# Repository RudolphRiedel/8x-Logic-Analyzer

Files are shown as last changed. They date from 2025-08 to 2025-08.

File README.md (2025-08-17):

# 8x-Logic-Analyzer

## what is this?
8 channel RP2350 logic analyzer hardware

This is a contribution project for: https://github.com/gusmanb/logicanalyzer
It might end up as a pull-request someday, however I am using version 6.5 which is still in beta.

## what the heck, why more hardware?

I was intrigued by logicanalyzer project, inexpensive, yet fast and with plenty of channels.
I have no use for 24 channels though, I did not like the daughter-board approach very much
and I had experience with 5V tolerant logic which makes switching the external reference obsolete.
Plus I had not done anything with the RP2350A before.

So I took this as an opportunity to design a RP2350A board.
Limited to 8 channels with no option to cascade, this is plenty for SPI plus four more pins.

I did two hardware revisions so far, the first is up and running, the second is functionally the same
with some details tweaked and I just ordered it.

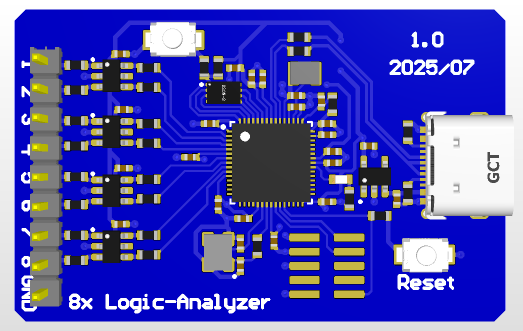
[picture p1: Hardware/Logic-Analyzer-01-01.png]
8x-Logic-Analyzer


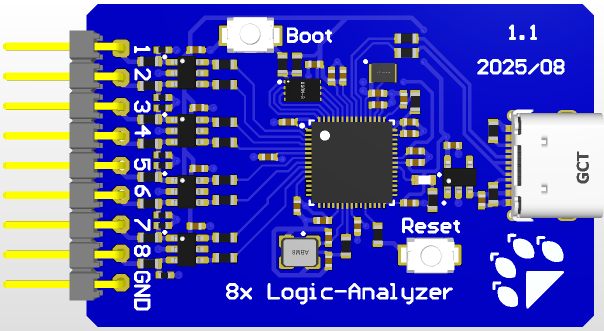
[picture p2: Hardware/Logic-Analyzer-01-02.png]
8x-Logic-Analyzer


This repository has the complete set of files for the Logic-Analyzer-01-02 design.
I just ordered five boards from JLCPCB with the gerber set Logic-Analyzer-01-02.zip, the BOM Logic-Analyzer-01-02_BOM.xlsx and the pick&place list Logic-Analyzer-01-02_CPL.xlsx.

There also is a .pdf included with the schematic: \Hardware\Logic-Analyzer-01-028x_Logic-Analyzer.PDF

## software?

This repository only has a modified version of the LogicAnaylzer_V2 firmware from the V6.5 branch.
I modified the files and added a new board: BOARD_PICO2_8X
To do that I changed CMakeLists.txt, LogicAnalyzer_Board_Settings.h, LogicAnalyzer_Build_Settings.cmake and publish.ps1
And with only 8 channels I was able to tweak the sample buffer from the original 384kiB to 469kiB.

As for the application, I am using the 6.5 beta that was made available here: https://github.com/gusmanb/logicanalyzer/discussions/277

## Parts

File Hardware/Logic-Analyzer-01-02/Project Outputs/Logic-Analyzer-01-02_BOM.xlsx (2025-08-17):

Comment | Designator | Footprint | JLCPCB Part #
100n | C100, C101, C102, C103, C104, C105, C106, C107, C108, C109, C110, C118, C119, C120, C121, C122, C123 | 0402 | C1525
15p | C111, C112 | 0402 | C1548
4µ7 | C113, C114, C115, C116, C117 | 0402 | C23733
red | D100 | 0603 | C2286
AOTA-B201610S3R3-101-T | L100 | 2.0mm x 1.6mm | C42411119
51 | R100, R101, R102, R103, R104, R105, R106, R107, R108, R109, R110, R111, R112, R113, R114, R115 | 0603 | C23197
27 | R116, R117, R121 | 0603 | C25190
1k | R118, R122, R124 | 0603 | C21190
5k1 | R119, R120 | 0603 | C23186
10k | R123, R125 | 0603 | C25804
100k | R126, R127, R128, R129, R130, R131, R132, R133 | 0402 | C25741
TS-1088-AR02016 | S100, S101 | 4x3 mm | C720477
74LVC2G17 | U100, U101, U103, U104 | SOT23-6 | C10429
TPLP5907MFX-3.3 | U102 | SOT23-5 | C5370990
XT25F16FDTIGT-S | U105 | USON8 | C29781641
RP2350A | U106 | QFN-60 | C42411118
12MHz | V100 | 3.2mm x 2.5mm | C20625731
1x9 2,54mm | X100 |  | do not populate
USB-C | X101 |  | C2765186

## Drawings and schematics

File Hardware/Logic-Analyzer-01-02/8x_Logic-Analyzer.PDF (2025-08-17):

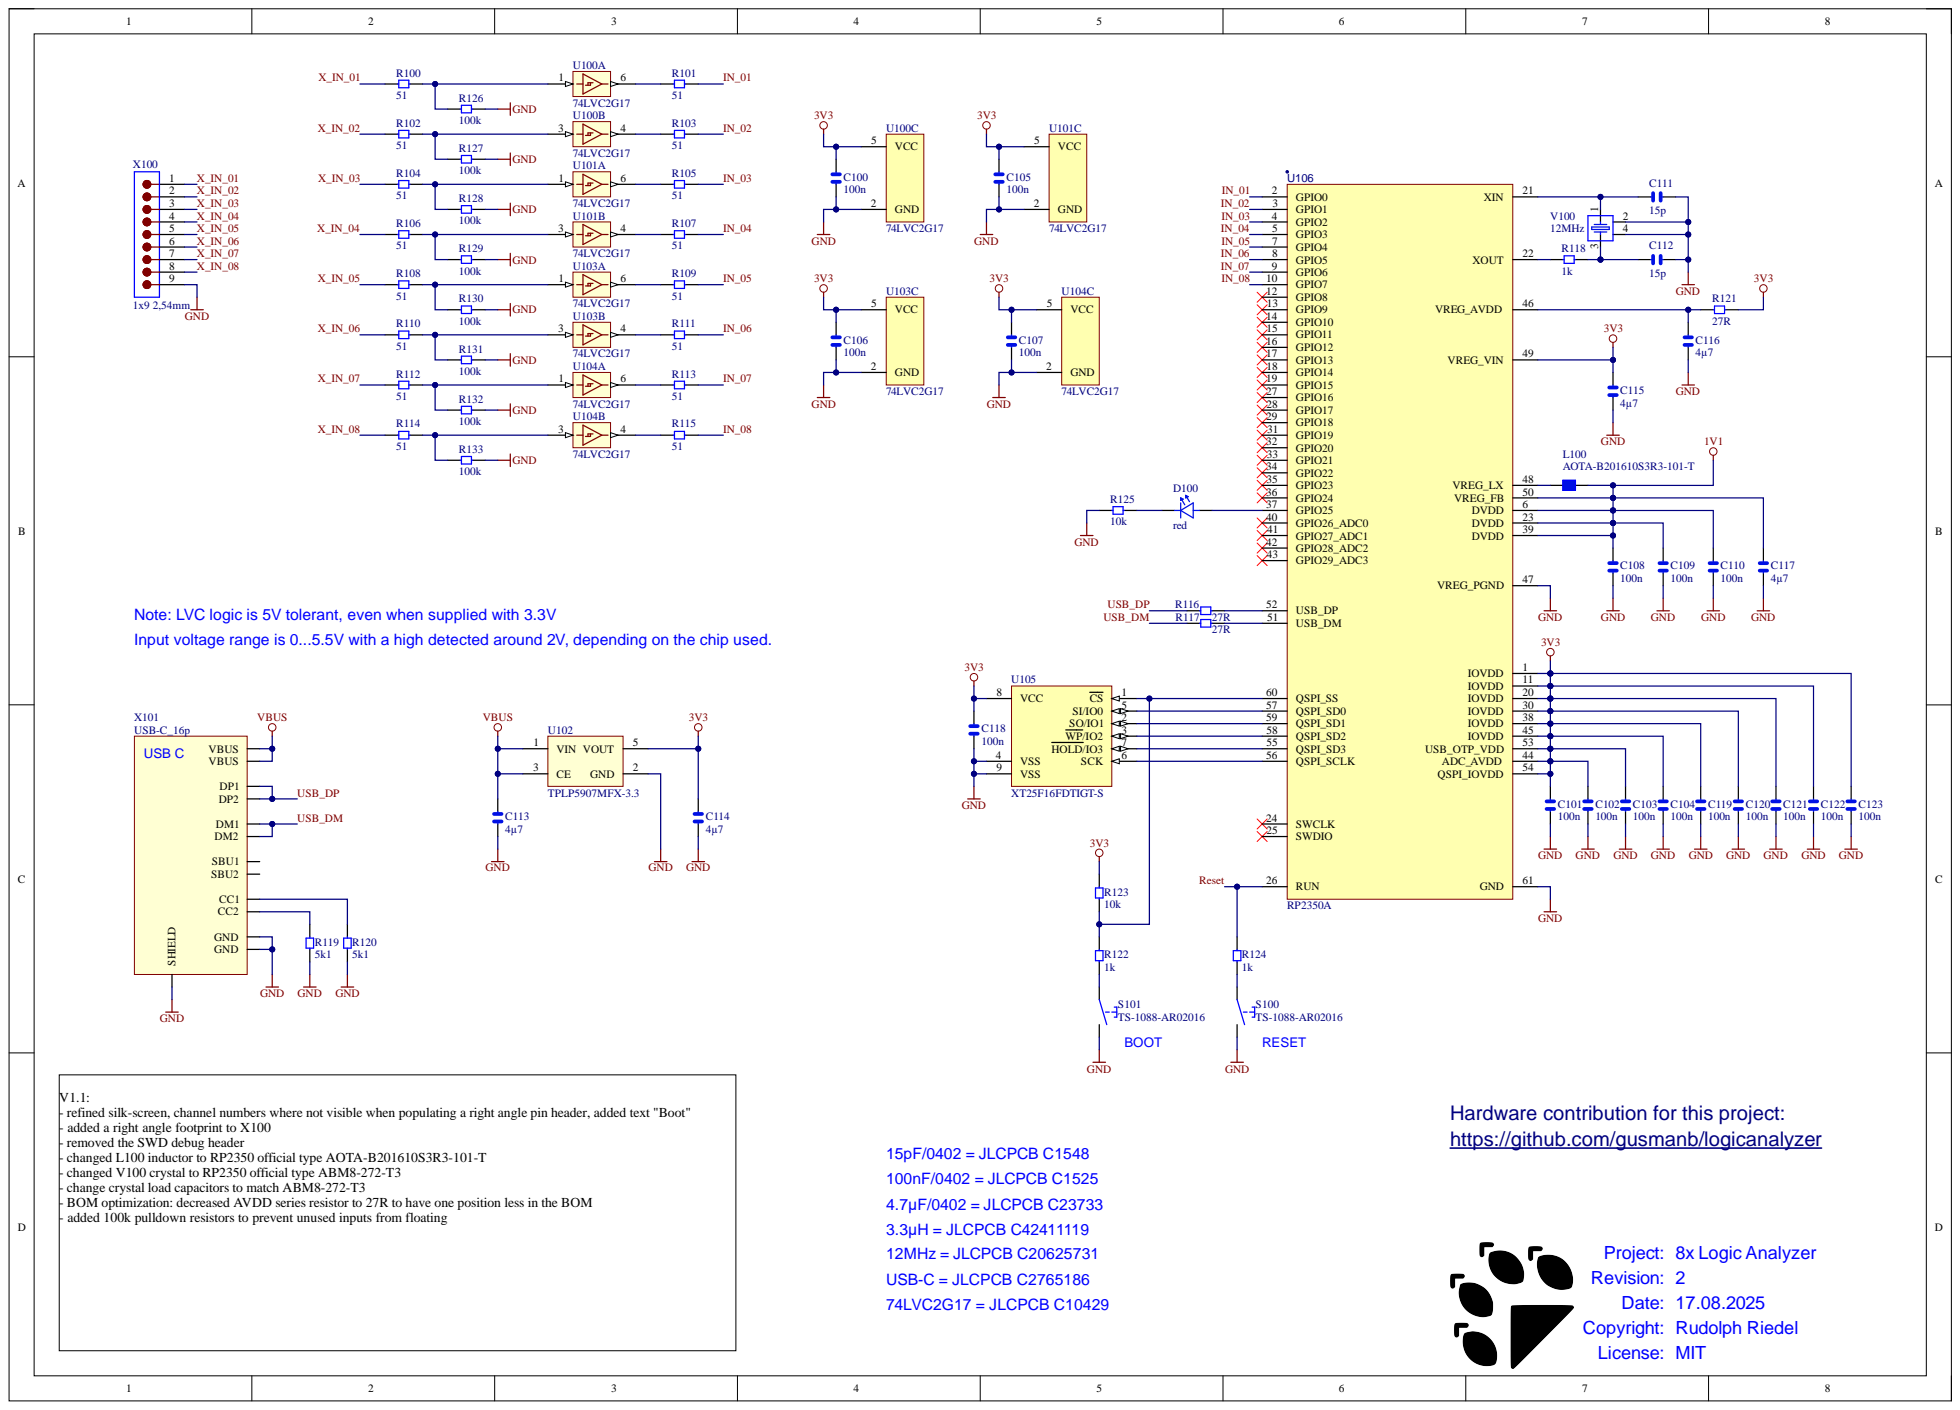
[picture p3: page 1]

LVC logic is 5V tolerant, even when
Note:
Input

voltage range is 0...5.5V with a high detected around 2V, depending on the

lk-screen, channel numbers

ing a right angle pin header

Hardware contribution for this project:
https://github.com/gusmanb/logicanalyz

to have one posi

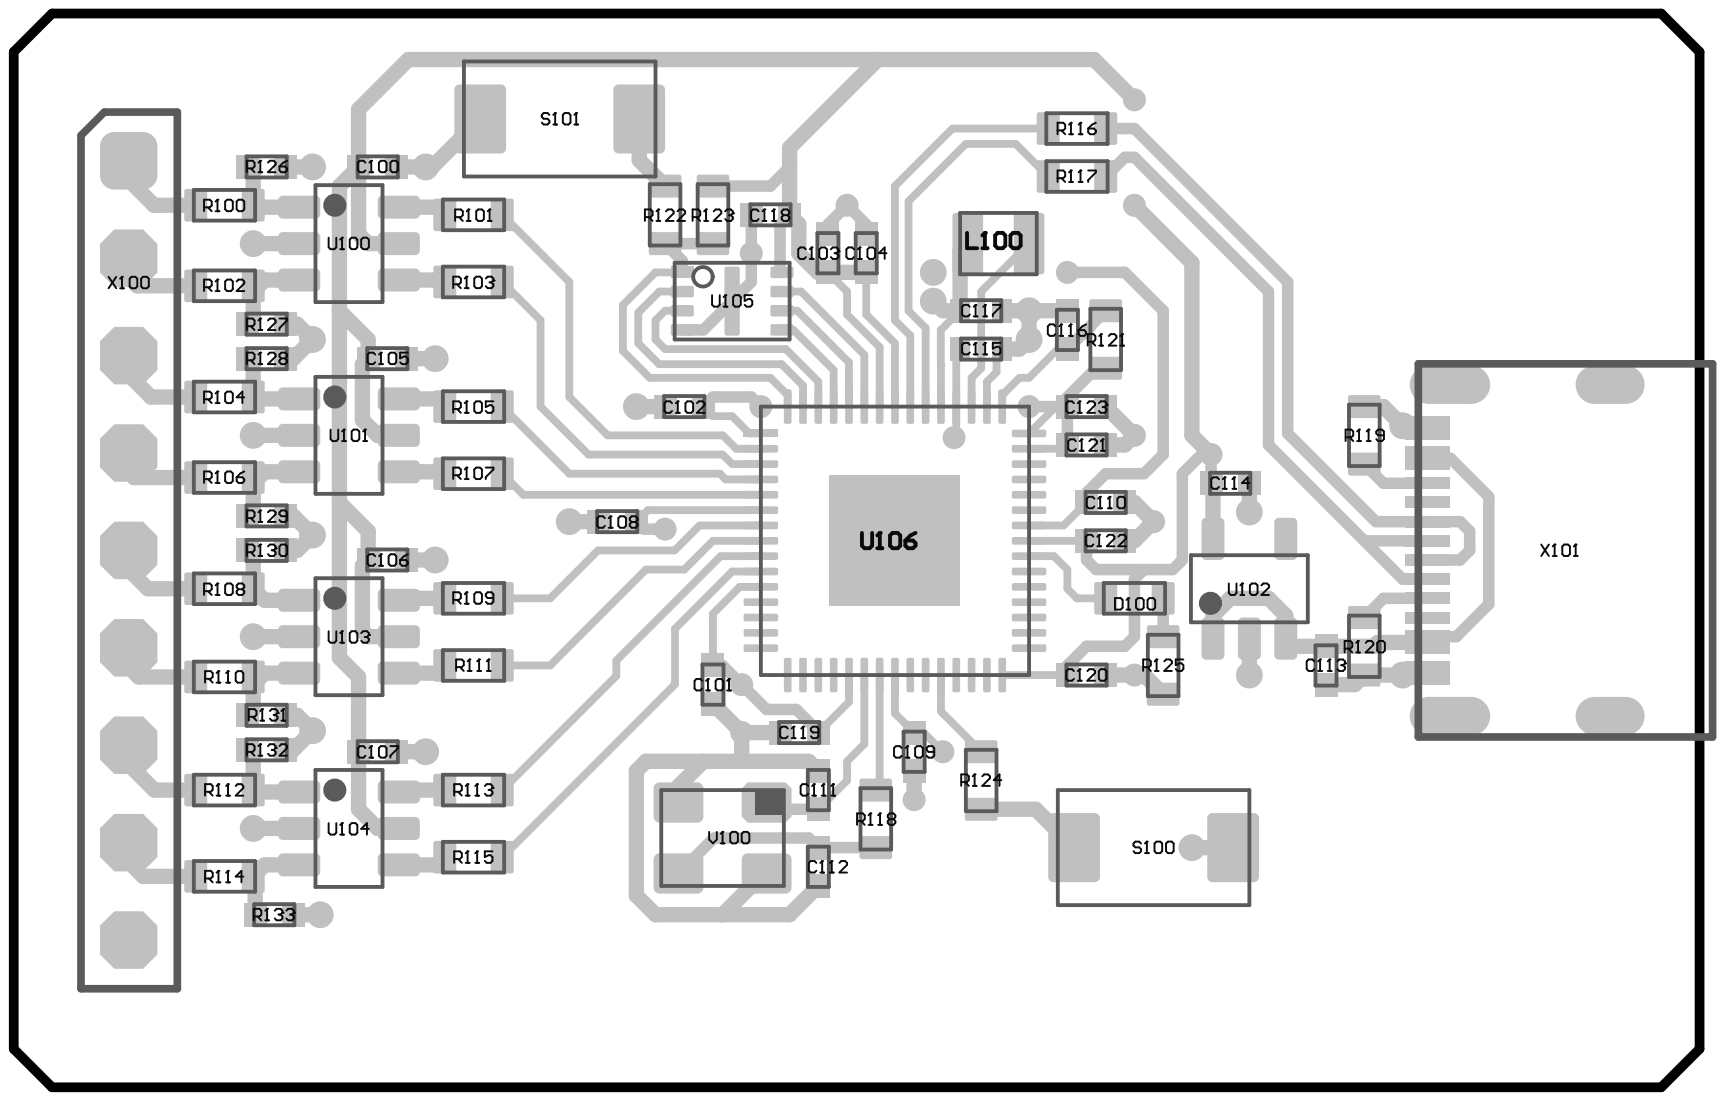
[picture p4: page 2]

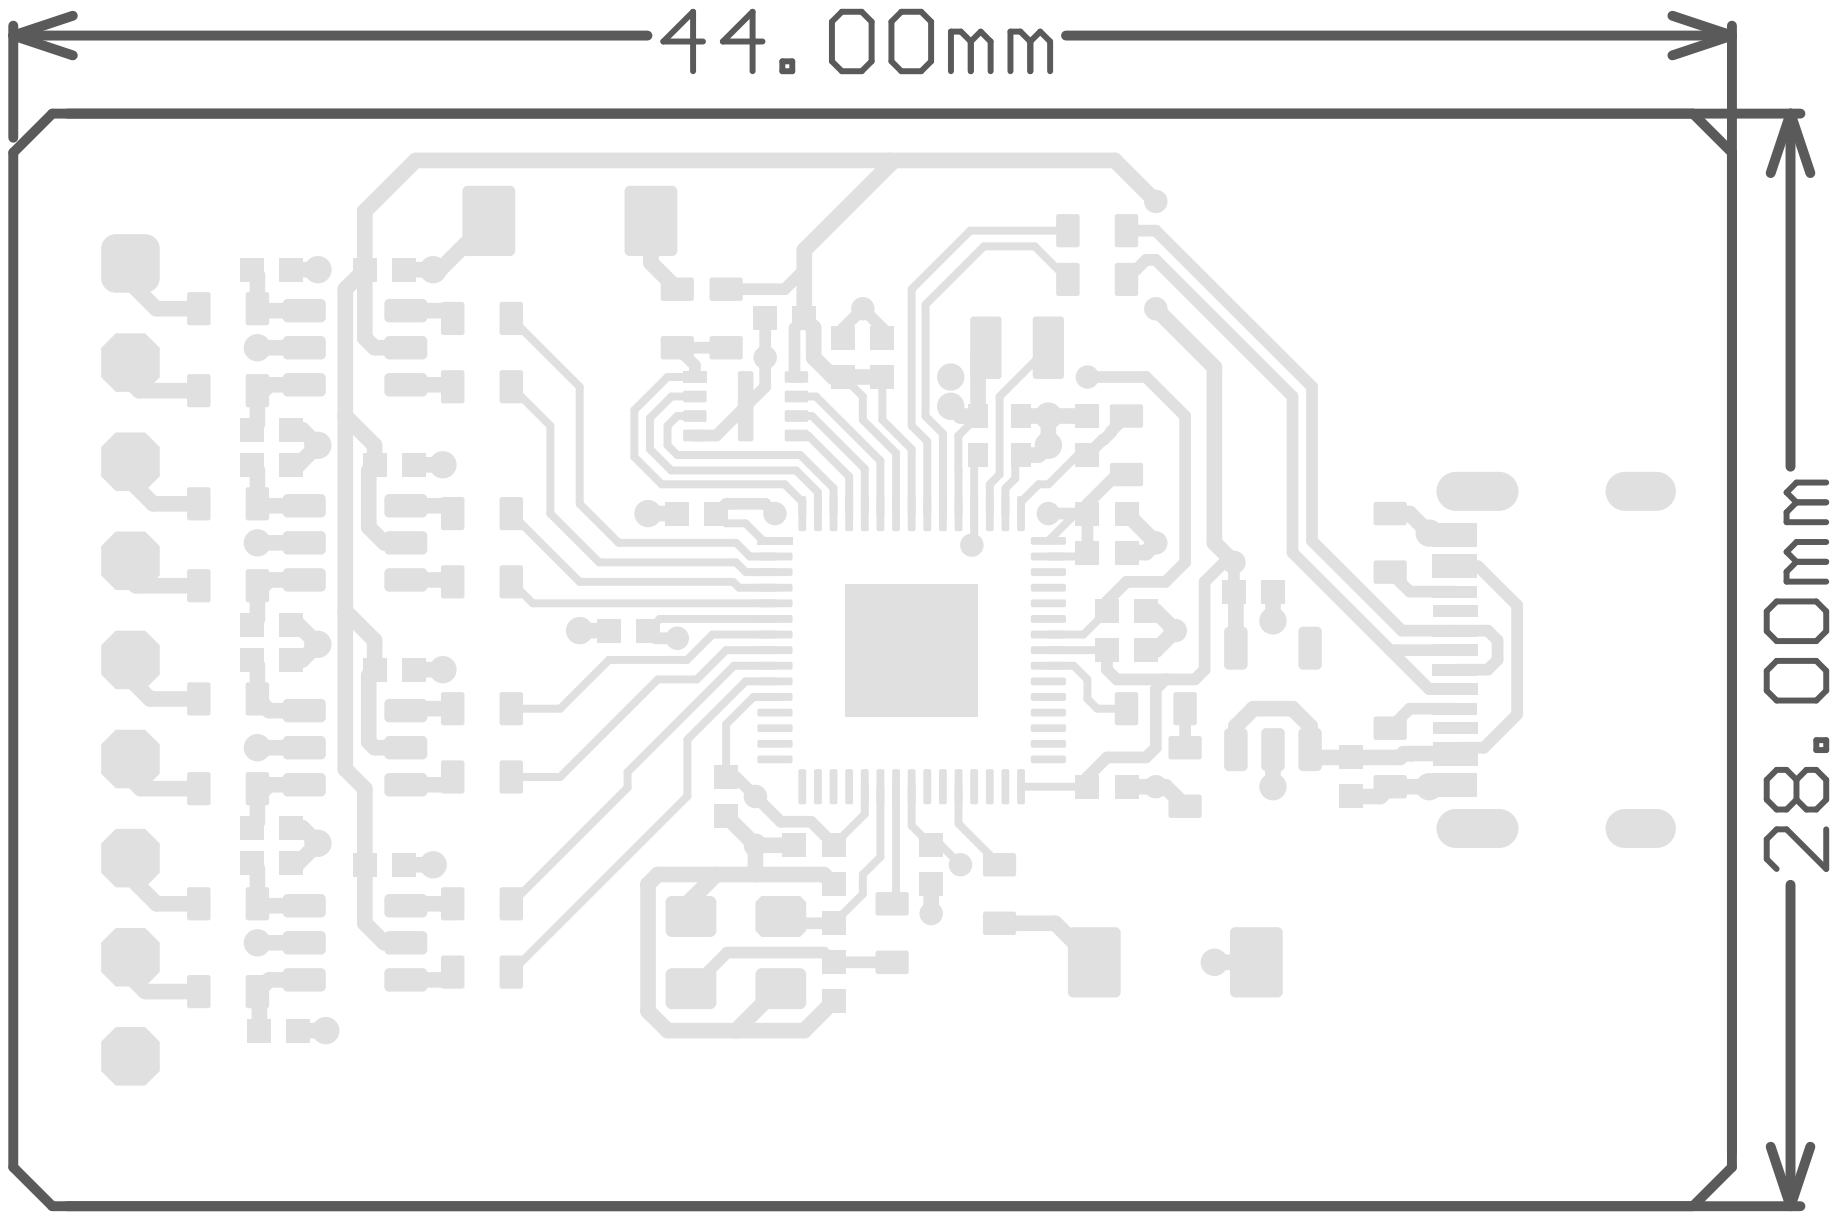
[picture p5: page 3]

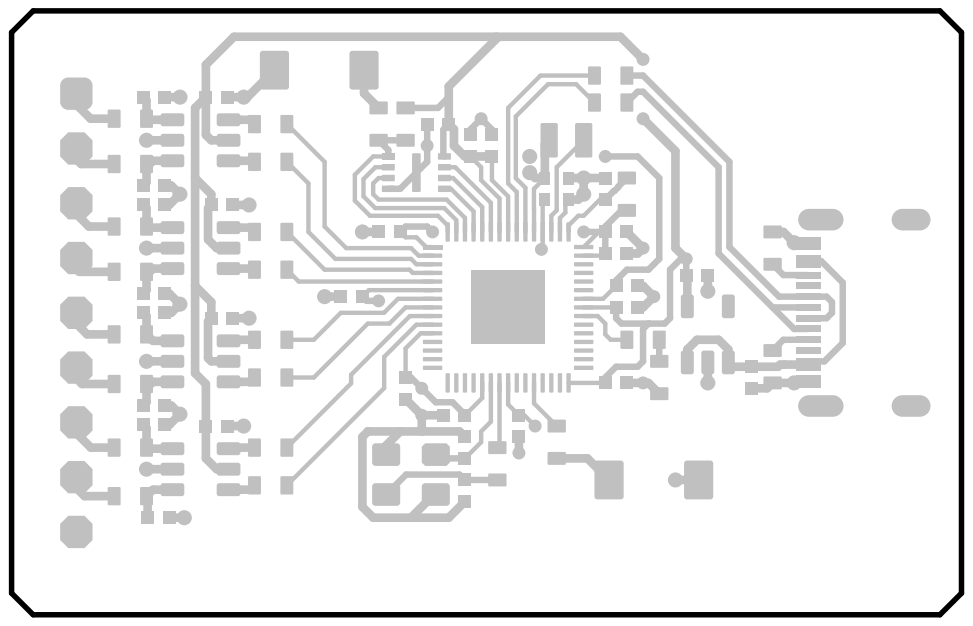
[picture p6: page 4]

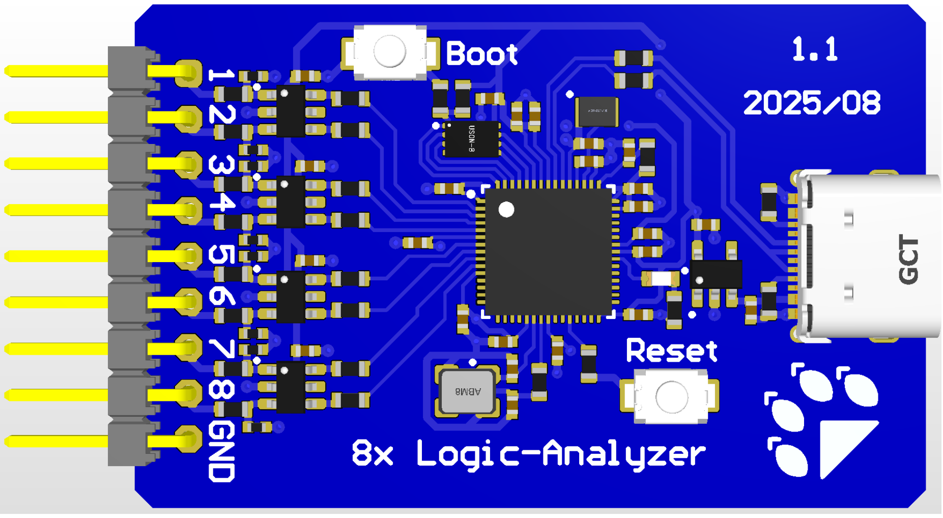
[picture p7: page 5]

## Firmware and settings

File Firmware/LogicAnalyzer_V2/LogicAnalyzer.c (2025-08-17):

#include "LogicAnalyzer_Board_Settings.h"

#include <stdio.h>
#include <string.h>
#include "pico/stdlib.h"
#include "hardware/dma.h"
#include "hardware/pio.h"
#include "hardware/clocks.h"
#include "hardware/flash.h"
#include "hardware/vreg.h"
#include "pico/multicore.h"
#include "LogicAnalyzer.pio.h"
#include "LogicAnalyzer_Structs.h"
#include "LogicAnalyzer_Capture.h"
#include "hardware/structs/syscfg.h"
#include "hardware/structs/systick.h"
#include "tusb.h"
#include "pico/unique_id.h"
#include "pico/bootrom.h"

#ifdef WS2812_LED
    #include "LogicAnalyzer_W2812.h"
#endif

#if defined (CYGW_LED) || defined(USE_CYGW_WIFI)

    #include "pico/cyw43_arch.h"

    #ifdef USE_CYGW_WIFI

        #include "Event_Machine.h"
        #include "Shared_Buffers.h"
        #include "LogicAnalyzer_WiFi.h"
        #include "hardware/regs/usb.h"
        #include "hardware/structs/usb.h"

        bool usbDisabled = false;
        bool cywReady = false;
        bool skipWiFiData = false;
        bool dataFromWiFi = false;
        EVENT_FROM_WIFI wifiEventBuffer;
        WIFI_SETTINGS_REQUEST* wReq;

        #define MULTICORE_LOCKOUT_TIMEOUT (uint64_t)10 * 365 * 24 * 60 * 60 * 1000 * 1000

    #endif

#endif

#if defined (GPIO_LED)
    #define INIT_LED() {\
                            gpio_init(LED_IO); \
                            gpio_set_dir(LED_IO, GPIO_OUT); \
                        }
    #define LED_ON() gpio_put(LED_IO, 1)
    #define LED_OFF() gpio_put(LED_IO, 0)
#elif defined (CYGW_LED)

    #define INIT_LED() { }

    #ifdef USE_CYGW_WIFI
        #define LED_ON() {\
        EVENT_FROM_FRONTEND lonEvt;\
        lonEvt.event = LED_ON;\
        event_push(&frontendToWifi, &lonEvt);\
        }

        #define LED_OFF() {\
        EVENT_FROM_FRONTEND loffEvt;\
        loffEvt.event = LED_OFF;\
        event_push(&frontendToWifi, &loffEvt);\
        }
    #else
        #define LED_ON() cyw43_arch_gpio_put(CYW43_WL_GPIO_LED_PIN, 1)
        #define LED_OFF() cyw43_arch_gpio_put(CYW43_WL_GPIO_LED_PIN, 0)
    #endif

#elif defined (WS2812_LED)
    #define INIT_LED() init_rgb()
    #define LED_ON() send_rgb(0,32,0)
    #define LED_OFF() send_rgb(0,0,32)
#elif defined (NO_LED)
    #define INIT_LED() { }
    #define LED_ON() { }
    #define LED_OFF() { }
#endif

//Buffer used to store received data
uint8_t messageBuffer[128];
//Position in the buffer
uint8_t bufferPos = 0;
//Capture status
bool capturing = false;

bool blink = false;
uint32_t blinkCount = 0;

//Capture request pointer
CAPTURE_REQUEST* req;

#ifdef USE_CYGW_WIFI

/// @brief Stores a new WiFi configuration in the flash of the device
/// @param settings Settings to store
void storeSettings(WIFI_SETTINGS* settings)
{
    uint8_t buffer[FLASH_PAGE_SIZE];
    memcpy(buffer, settings, sizeof(WIFI_SETTINGS));
    //multicore_lockout_start_blocking ();
    multicore_lockout_start_timeout_us(MULTICORE_LOCKOUT_TIMEOUT);

    uint32_t intStatus = save_and_disable_interrupts();

    flash_range_erase(FLASH_SETTINGS_OFFSET, FLASH_SECTOR_SIZE);

    for(int buc = 0; buc < 1000; buc++)
    {
        asm("nop");
        asm("nop");
        asm("nop");
        asm("nop");
        asm("nop");
    }

    flash_range_program(FLASH_SETTINGS_OFFSET, buffer, FLASH_PAGE_SIZE);

    for(int buc = 0; buc < 1000; buc++)
    {
        asm("nop");
        asm("nop");
        asm("nop");
        asm("nop");
        asm("nop");
    }

    restore_interrupts(intStatus);

    bool unlocked = false;

    do {
        unlocked = multicore_lockout_end_timeout_us(MULTICORE_LOCKOUT_TIMEOUT);
    } while(!unlocked);

    sleep_ms(500);

}

#endif

/// @brief Sends a response message to the host application in string mode
/// @param response The message to be sent (null terminated)
/// @param toWiFi If true the message is sent to a WiFi endpoint, else to the USB connection through STDIO
void sendResponse(const char* response, bool toWiFi)
{
    #ifdef USE_CYGW_WIFI
    if(toWiFi)
    {
        EVENT_FROM_FRONTEND evt;
        evt.event = SEND_DATA;
        evt.dataLength = strlen(response);
        memset(evt.data, 0, 32);
        memcpy(evt.data, response, evt.dataLength);
        event_push(&frontendToWifi, &evt);
    }
    else
    #endif
        printf(response);
}

/// @brief Transfer a buffer of data through USB using the TinyUSB CDC functions
/// @param data Buffer of data to transfer
/// @param len Length of the buffer
void cdc_transfer(unsigned char* data, int len)
{

    int left = len;
    int pos = 0;

    while(left > 0)
    {
        int avail = (int) tud_cdc_write_available();

        if(avail > left)
            avail = left;

        if(avail)
        {
            int transferred = (int) tud_cdc_write(data + pos, avail);
            tud_task();
            tud_cdc_write_flush();
            
            pos += transferred;
            left -= transferred;
        }
        else
        {
            tud_task();
            tud_cdc_write_flush();
            if (!tud_cdc_connected())
                break;
        }
    }
}

/// @brief Processes data received from the host application
/// @param data The received data
/// @param length Length of the data
/// @param fromWiFi If true the message comes from a WiFi connection
void processData(uint8_t* data, uint length, bool fromWiFi)
{
    for(uint pos = 0; pos < length; pos++)
    {
        //Store char in buffer and increment position
        messageBuffer[bufferPos++] = data[pos];
        
        //If we have stored the first byte and it is not 0x55 restart reception
        if(bufferPos == 1 && messageBuffer[0] != 0x55)
            bufferPos = 0;
        else if(bufferPos == 2 && messageBuffer[1] != 0xAA) //If we have stored the second byte and it is not 0xAA restart reception
            bufferPos = 0;
        else if(bufferPos >= 256) //Have we overflowed the buffer? then inform to the host and restart reception
        {
            sendResponse("ERR_MSG_OVERFLOW\n", fromWiFi);
            bufferPos = 0;
        }
        else if(bufferPos > 2) //Try to parse the data
        {
            if(messageBuffer[bufferPos - 2] == 0xAA && messageBuffer[bufferPos - 1] == 0x55) //Do we have the stop condition?
            {

                //Yes, unescape the buffer,
                int dest = 0;

                for(int src = 0; src < bufferPos; src++)
                {
                    if(messageBuffer[src] == 0xF0)
                    {
                        messageBuffer[dest] = messageBuffer[src + 1] ^ 0xF0;
                        src++;
                    }
                    else
                        messageBuffer[dest] = messageBuffer[src];

                    dest++;
                }

                switch(messageBuffer[2]) //Check the command we received
                {

                    case 0: //ID request

                        if(bufferPos != 5) //Malformed message?
                            sendResponse("ERR_UNKNOWN_MSG\n", fromWiFi);
                        else
                        {
                            sendResponse("LOGIC_ANALYZER_"BOARD_NAME"_"FIRMWARE_VERSION"\n", fromWiFi);

                            char msg[64];
                            
                            sprintf(msg, "FREQ:%d\n", MAX_FREQ);
                            sendResponse(msg, fromWiFi);
                            sprintf(msg, "BLASTFREQ:%d\n", MAX_BLAST_FREQ);
                            sendResponse(msg, fromWiFi);
                            sprintf(msg, "BUFFER:%d\n", CAPTURE_BUFFER_SIZE);
                            sendResponse(msg, fromWiFi);
                            sprintf(msg, "CHANNELS:%d\n", MAX_CHANNELS);
                            sendResponse(msg, fromWiFi);
                        }
                        break;

                    case 1: //Capture request
                        
                        req = (CAPTURE_REQUEST*)&messageBuffer[3]; //Get the request pointer
                        
                        bool started = false;

                        #ifdef SUPPORTS_COMPLEX_TRIGGER

                            if(req->triggerType == 1) //Start complex trigger capture
                                started = StartCaptureComplex(req->frequency, req->preSamples, req->postSamples, (uint8_t*)&req->channels, req->channelCount, req->trigger, req->count, req->triggerValue, req->captureMode);
                            else if(req->triggerType == 2) //start fast trigger capture
                                started = StartCaptureFast(req->frequency, req->preSamples, req->postSamples, (uint8_t*)&req->channels, req->channelCount, req->trigger, req->count, req->triggerValue, req->captureMode);
                            else if(req->triggerType == 3)
                                started = StartCaptureBlast(req->frequency, req->postSamples, (uint8_t*)&req->channels, req->channelCount, req->trigger, req->inverted, req->captureMode);
                            else //Start simple trigger capture
                                started = StartCaptureSimple(req->frequency, req->preSamples, req->postSamples, req->loopCount, req->measure, (uint8_t*)&req->channels, req->channelCount, req->trigger, req->inverted, req->captureMode);
                        
                        #else

                            if(req->triggerType == 1 || req->triggerType == 2)
                            {
                                sendResponse("CAPTURE_ERROR\n", fromWiFi);
                                break;
                            }
                            else if(req->triggerType == 3)
                                started = StartCaptureBlast(req->frequency, req->postSamples, (uint8_t*)&req->channels, req->channelCount, req->trigger, req->inverted, req->captureMode);
                            else //Start simple trigger capture
                                started = StartCaptureSimple(req->frequency, req->preSamples, req->postSamples, req->loopCount, req->measure, (uint8_t*)&req->channels, req->channelCount, req->trigger, req->inverted, req->captureMode);
                        
                        #endif

                        if(started) //If started successfully inform to the host
                        {
                            sendResponse("CAPTURE_STARTED\n", fromWiFi);
                            capturing = true;
                        }
                        else
                            sendResponse("CAPTURE_ERROR\n", fromWiFi); //Else notify the error

                        break;
                    
                    #ifdef USE_CYGW_WIFI

                    case 2: //Update WiFi settings

                        wReq = (WIFI_SETTINGS_REQUEST*)&messageBuffer[3];
                        WIFI_SETTINGS settings;
                        settings.checksum = 0;
                        memcpy(settings.apName, wReq->apName, 33);
                        memcpy(settings.passwd, wReq->passwd, 64);
                        memcpy(settings.ipAddress, wReq->ipAddress, 16);
                        settings.port = wReq->port;

                        for(int buc = 0; buc < 33; buc++)
                            settings.checksum += settings.apName[buc];

                        for(int buc = 0; buc < 64; buc++)
                            settings.checksum += settings.passwd[buc];

                        for(int buc = 0; buc < 16; buc++)
                            settings.checksum += settings.ipAddress[buc];

                        settings.checksum += settings.port;

                        settings.checksum += 0x0f0f;

                        storeSettings(&settings);

                        wifiSettings = settings;

                        EVENT_FROM_FRONTEND evt;
                        evt.event = CONFIG_RECEIVED;
                        event_push(&frontendToWifi, &evt);

                        sendResponse("SETTINGS_SAVED\n", fromWiFi);

                        break;

                    case 3: //Read power status

                        if(!fromWiFi)
                            sendResponse("ERR_UNSUPPORTED\n", fromWiFi);
                        else 
                        {
                            EVENT_FROM_FRONTEND powerEvent;
                            powerEvent.event = GET_POWER_STATUS;
                            event_push(&frontendToWifi, &powerEvent);
                        }
                        
                        break;

                    #else

                    case 2:
                    case 3:

                        sendResponse("ERR_UNSUPPORTED\n", fromWiFi);
                        break;

                    #endif

                    case 4:

                        sendResponse("RESTARTING_BOOTLOADER\n", fromWiFi);
                        sleep_ms(1000);
                        reset_usb_boot(0, 0);
                        break;

                    case 5:

                        blink = true;
                        blinkCount = 0;
                        sendResponse("BLINKON\n", fromWiFi);
                        break;

                    case 6:

                        blink = false;
                        blinkCount = 0;
                        sendResponse("BLINKOFF\n", fromWiFi);
                        LED_ON();
                        break;

                    default:

                        sendResponse("ERR_UNKNOWN_MSG\n", fromWiFi); //Unknown message
                        break;

                }

                bufferPos = 0; //Reset buffer position
            }
        }

    }

    //PROTOCOL EXPLAINED:
    //
    //The protocol is very basic, it receives binary frames and sends strings terminated by a carriage return.
    //
    //Each binary frame has a start and an end condition, being these two secuences of two bytes:
    // start condition: 0x55 0xAA
    // stop condition: 0xAA 0x55
    //
    //This kind of framing can cause problems if the packets contain the frame condition bytes, there needs to be implemented
    //a scape character to avoid this.The char 0xF0 is used as escape character. Escaping is done by XOR'ing the scape character 
    //with the scaped char. For example, if we need to send 0xAA we would send { 0xF0, 0x5A }, which is 0xAA XOR 0xF0 = 0x5A. 
    //In case of sending the scape char we would send { 0xF0, 0x00 }.
    //
    //Inside each frame we have a command byte and additional data. Based on the command a binary struct will be deserialized
    //from the buffer. Right now the protocol has only two commands: ID request and capture request. ID request does not
    //have any data, but the capture request has a CAPTURE_REQUEST struct as data.
}
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
int main()
{
    #if defined (TURBO_MODE)

        vreg_disable_voltage_limit();
        vreg_set_voltage(VREG_VOLTAGE_1_30);
        sleep_ms(100);
        
        //Overclock Powerrrr!
        set_sys_clock_khz(400000, true);
    
    #else

        set_sys_clock_khz(200000, true);

    #endif

    //Enable systick using CPU clock
    systick_hw->csr = 0x05;

    pico_unique_board_id_t id;
    pico_get_unique_board_id(&id);

    uint16_t delay = 0;

    for(int buc = 0; buc < PICO_UNIQUE_BOARD_ID_SIZE_BYTES; buc++)
        delay += id.id[buc];

    delay = (delay & 0x3ff) + ((delay & 0xFC00) >> 6);

    sleep_ms(delay);

    //Initialize USB stdio
    stdio_init_all();

    #if defined (BUILD_PICO_W) || defined (BUILD_PICO_2_W)
        cyw43_arch_init();
    #elif defined (BUILD_PICO_W_WIFI) || defined (BUILD_PICO_2_W_WIFI)
        event_machine_init(&wifiToFrontend, wifiEvent, sizeof(EVENT_FROM_WIFI), 8);
            multicore_launch_core1(runWiFiCore);
            while(!cywReady)
                event_process_queue(&wifiToFrontend, &wifiEventBuffer, 1);
    #endif

    //A bit of delay, if the program tries to send data before Windows has identified the device it may crash
    sleep_ms(1000);

    //Clear message buffer
    memset(messageBuffer, 0, 128);

    //Configure led
    INIT_LED();
    LED_ON();

    while(1)
    {
        //Are we capturing?
        if(capturing)
        {
            //Is the PIO units still working?
            if(!IsCapturing())
            {
                //Retrieve the capture buffer and get info about it.
                uint32_t length, first;
                CHANNEL_MODE mode;
                uint8_t* buffer = GetBuffer(&length, &first, &mode);

                uint8_t stampsLength;
                volatile uint32_t* timestamps = GetTimestamps(&stampsLength);

                //Send the data to the host
                uint8_t* lengthPointer = (uint8_t*)&length;

                //Send capture length
                

                #ifdef USE_CYGW_WIFI

                    if(usbDisabled)
                    {
                        sleep_ms(2000);
                        EVENT_FROM_FRONTEND evt;
                        evt.event = SEND_DATA;
                        evt.dataLength = 4;
                        memcpy(evt.data, lengthPointer, 4);
                        event_push(&frontendToWifi, &evt);
                    }
                    else
                    {
                        sleep_ms(100);
                        cdc_transfer(lengthPointer, 4);
                    }

                #else
                    sleep_ms(100);
                    cdc_transfer(lengthPointer, 4);
                #endif

                sleep_ms(100);

                //Tanslate sample numbers to byte indexes, makes easier to send data
                switch(mode)
                {
                    case MODE_16_CHANNEL:
                        length *= 2;
                        first *= 2;
                        break;
                    case MODE_24_CHANNEL:
                        length *= 4;
                        first *= 4;
                        break;
                }

                #ifdef USE_CYGW_WIFI

                    //Send the samples
                    if(usbDisabled)
                    {
                        EVENT_FROM_FRONTEND evt;
                        evt.event = SEND_DATA;

                        int pos = 0;
                        int filledData;
                        while(pos < length)
                        {
                            filledData = 0;
                            while(pos < length && filledData < 32)
                            {
                                evt.data[filledData] = buffer[first++];

                                if(first >= 131072)
                                    first = 0;

                                pos++;
                                filledData++;
                            }

                            evt.dataLength = filledData;
                            event_push(&frontendToWifi, &evt);
                        }

                        evt.data[0] = stampsLength;
                        evt.dataLength = 1;
                        event_push(&frontendToWifi, &evt);

                        for(int buc = 0; buc < stampsLength; buc++)
                        {
                            *((uint32_t*)evt.data) = timestamps[buc];
                            evt.dataLength = 4;
                            event_push(&frontendToWifi, &evt);
                        }
                    }
                    else
                    {
                        if(first + length > CAPTURE_BUFFER_SIZE)
                        {
                            cdc_transfer(buffer + first, CAPTURE_BUFFER_SIZE - first);
                            cdc_transfer(buffer, (first + length) - CAPTURE_BUFFER_SIZE);
                        }
                        else
                            cdc_transfer(buffer + first, length);

                        cdc_transfer(&stampsLength, 1);

                        if(stampsLength > 1)
                            cdc_transfer((unsigned char*)timestamps, stampsLength * 4);
                    }
                #else

                    if(first + length > CAPTURE_BUFFER_SIZE)
                    {
                        cdc_transfer(buffer + first, CAPTURE_BUFFER_SIZE - first);
                        cdc_transfer(buffer, (first + length) - CAPTURE_BUFFER_SIZE);
                    }
                    else
                        cdc_transfer(buffer + first, length);

                    cdc_transfer(&stampsLength, 1);
                        
                    if(stampsLength > 1)
                        cdc_transfer((unsigned char*)timestamps, stampsLength * 4);

                #endif
                //Done!
                capturing = false;
            }
            else
            {
                LED_OFF();
                sleep_ms(1000);

                //Check for cancel request
                if(processCancel())
                {
                    //Stop capture
                    StopCapture();
                    capturing = false;
                    LED_ON();
                }
                else
                {
                    LED_ON();
                    #ifdef SUPPORTS_COMPLEX_TRIGGER
                    check_fast_interrupt();
                    #endif
                    sleep_ms(1000);
                }
            }
        }
        else
        {
            if(blink)
            {
                if(blinkCount++ == 200000)
                {
                    LED_OFF();
                }
                else if(blinkCount == 400000)
                {
                    LED_ON();
                    blinkCount = 0;
                }
            }

            processInput(); //Read incomming data
        }
    }

    return 0;
}

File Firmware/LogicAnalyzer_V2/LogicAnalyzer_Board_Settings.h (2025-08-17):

#ifndef __LOGICANALYZER_BOARD_SETTINGS__

    #define __LOGICANALYZER_BOARD_SETTINGS__

    #include "pico/stdlib.h"
    //#include "LogicAnalyzer_Build_Settings.h"

    //Board definitions

    //This defines the name sent to the software
    //#define BOARD_NAME "PICO"

    //If defined the device supports complex, fast and external triggers
    //#define SUPPORTS_COMPLEX_TRIGGER

    //Stablishes the channel base GPIO
    //#define INPUT_PIN_BASE 2

    //Complex/fast/ext trigger output pin
    //#define COMPLEX_TRIGGER_OUT_PIN 0

    //Complex/fast/ext trigger input pin
    //#define COMPLEX_TRIGGER_IN_PIN 1

    //If defined, the onboard led is a led connected to a GPIO
    //#define GPIO_LED

    //If defined, the onboard led is a led connected to a CYGW module (for the Pico W)
    //#define CYGW_LED

    //If defined, the onboard led is a RGB led connected to a GPIO
    //#define WS2812_LED

    //If defined, the board has no LED
    //#define NO_LED

    //Defines the used GPIO used for the GPIO and WS2812 led types
    //#define LED_IO 25

    //If defined enables the Pico W WiFi module
    //#define USE_CYGW_WIFI

    //Defines the pin map for the PIO
    //Include ALWAYS an entry for the COMPLEX_TRIGGER_IN_PIN even if not used, you can repeat a pin if needed
    //If COMPLEX_TRIGGER is supported remember to set the first 16 channels to be consecutive
    //#define PIN_MAP {2,3,4,5,6,7,8,9,10,11,12,13,14,15,16,17,18,19,20,21,22,26,27,28,COMPLEX_TRIGGER_IN_PIN}

    //Defines the maximum capture buffer size
    //#define CAPTURE_BUFFER_SIZE (128 * 1024)

    //Defines the maximum number of channels
    //#define MAX_CHANNELS 24

    //Defines the maximum frequency for the capture in normal mode
    //#define MAX_FREQ 200000000

    //Defines the maximum frequency for the capture in blast mode
    //#define MAX_BLAST_FREQ 400000000

    //If the board supports TURBO mode (400Mhz overclock) then you can define two sets of frequencies using
    //#ifdef TURBO_MODE / #else / #endif

    #if defined (BUILD_PICO)

        #define BOARD_NAME "PICO"
        #define SUPPORTS_COMPLEX_TRIGGER
        #define INPUT_PIN_BASE 2
        #define COMPLEX_TRIGGER_OUT_PIN 0
        #define COMPLEX_TRIGGER_IN_PIN 1
        #define GPIO_LED
        #define LED_IO 25
        #define PIN_MAP {2,3,4,5,6,7,8,9,10,11,12,13,14,15,16,17,18,19,20,21,22,26,27,28,COMPLEX_TRIGGER_IN_PIN}

        #ifdef TURBO_MODE
            #define MAX_FREQ 200000000
            #define MAX_BLAST_FREQ 400000000
        #else
            #define MAX_FREQ 100000000
            #define MAX_BLAST_FREQ 200000000
        #endif
        #define CAPTURE_BUFFER_SIZE (128 * 1024)
        #define MAX_CHANNELS 24

    #elif defined (BUILD_PICO_2)

        #define BOARD_NAME "PICO_2"
        #define SUPPORTS_COMPLEX_TRIGGER
        #define INPUT_PIN_BASE 2
        #define COMPLEX_TRIGGER_OUT_PIN 0
        #define COMPLEX_TRIGGER_IN_PIN 1
        #define GPIO_LED
        #define LED_IO 25
        #define PIN_MAP {2,3,4,5,6,7,8,9,10,11,12,13,14,15,16,17,18,19,20,21,22,26,27,28,COMPLEX_TRIGGER_IN_PIN}

        #ifdef TURBO_MODE
            #define MAX_FREQ 200000000
            #define MAX_BLAST_FREQ 400000000
        #else
            #define MAX_FREQ 100000000
            #define MAX_BLAST_FREQ 200000000
        #endif
        #define CAPTURE_BUFFER_SIZE (128 * 3 * 1024)
        #define MAX_CHANNELS 24

    #elif defined (BUILD_PICO_W)

        #define BOARD_NAME "W"
        #define SUPPORTS_COMPLEX_TRIGGER
        #define INPUT_PIN_BASE 2
        #define COMPLEX_TRIGGER_OUT_PIN 0
        #define COMPLEX_TRIGGER_IN_PIN 1
        #define CYGW_LED
        #define PIN_MAP {2,3,4,5,6,7,8,9,10,11,12,13,14,15,16,17,18,19,20,21,22,26,27,28,COMPLEX_TRIGGER_IN_PIN}

        #define MAX_FREQ 100000000
        #define MAX_BLAST_FREQ 200000000
        #define CAPTURE_BUFFER_SIZE (128 * 1024)
        #define MAX_CHANNELS 24

    #elif defined (BUILD_PICO_W_WIFI)

        #define BOARD_NAME "WIFI"
        #define SUPPORTS_COMPLEX_TRIGGER
        #define INPUT_PIN_BASE 2
        #define COMPLEX_TRIGGER_OUT_PIN 0
        #define COMPLEX_TRIGGER_IN_PIN 1
        #define CYGW_LED
        #define USE_CYGW_WIFI
        #define PIN_MAP {2,3,4,5,6,7,8,9,10,11,12,13,14,15,16,17,18,19,20,21,22,26,27,28,COMPLEX_TRIGGER_IN_PIN}
        #define MAX_FREQ 100000000
        #define MAX_BLAST_FREQ 200000000
        #define CAPTURE_BUFFER_SIZE (128 * 1024)
        #define MAX_CHANNELS 24

    #elif defined (BUILD_PICO_2_W)

        #define BOARD_NAME "2_W"
        #define SUPPORTS_COMPLEX_TRIGGER
        #define INPUT_PIN_BASE 2
        #define COMPLEX_TRIGGER_OUT_PIN 0
        #define COMPLEX_TRIGGER_IN_PIN 1
        #define CYGW_LED
        #define PIN_MAP {2,3,4,5,6,7,8,9,10,11,12,13,14,15,16,17,18,19,20,21,22,26,27,28,COMPLEX_TRIGGER_IN_PIN}
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
